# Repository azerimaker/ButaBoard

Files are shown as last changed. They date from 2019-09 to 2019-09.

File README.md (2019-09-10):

# ButaBoard
This repo contains all the necessary design, fabrication files and example codes for the ButaBoard development board. ButaBoard is highly inspired by the [Adafruit Circuit Playground Classic](https://www.adafruit.com/product/3000) with some minor hardware changes. Additionaly, the paisley patterned styling and ornamental touches make this board more suitable for wearables. 

## Specs:
- ATmega32u4 MCU, running @3.3V, 8MHz
- 32KB Flash, 2.5 KB SRAM, 1KB EEPROM
- IO pins: 14 (Crocodile clip-4mm Banana pads)
- On-board peripherals:
  - LIS3DH Accelerometer 
  - ALS-PT19-315C analog light sensor
  - AOS3729A analog microphone
  - NTC Temperature Sensor
  - Buzzer
  - 12x WS2812B RGB LEDs
  - 1x user button, 1x user LED
  - Power Switch
- Dimenions: ~94x61x5 mm

### ButaBoard v1
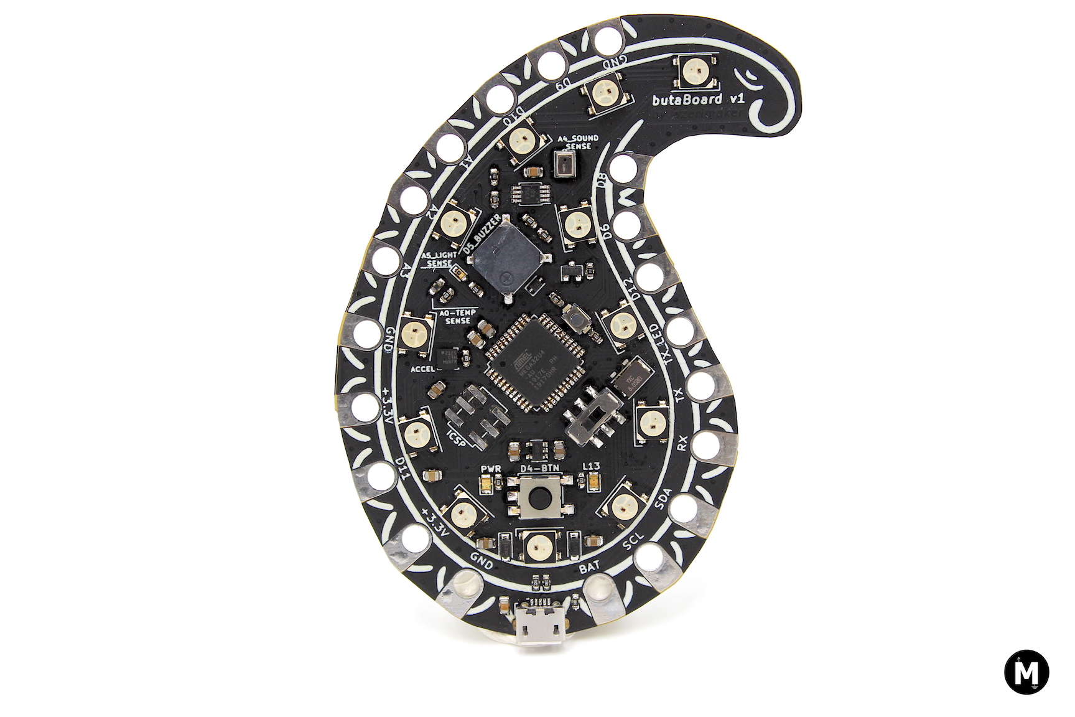
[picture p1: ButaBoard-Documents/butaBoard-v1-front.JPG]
ButaBoard v1 Front

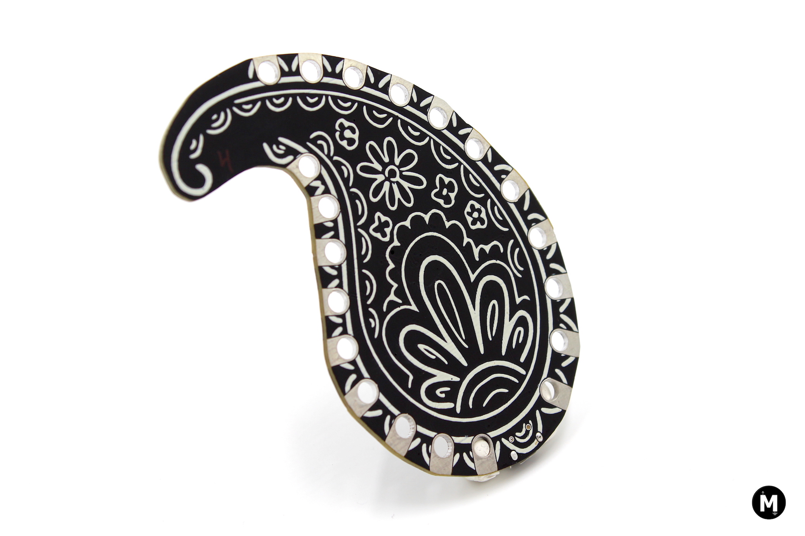
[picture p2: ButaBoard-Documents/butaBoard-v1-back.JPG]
ButaBoard v1 Back


<div align="center">
<br />This work is licensed under a <a rel="license" href="http://creativecommons.org/licenses/by-nc-sa/4.0/">Creative Commons Attribution-NonCommercial-ShareAlike 4.0 International License</a>.
</div>

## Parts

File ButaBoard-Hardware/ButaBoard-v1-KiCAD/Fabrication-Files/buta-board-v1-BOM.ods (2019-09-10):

Reference | Quantity | MPN | Value | Description | Package | URL
C11 | 1 |  | 100nF |  | 0805_2012Metric | ~
C2 C6 C1 C5 C10 | 5 |  | 1uF |  | 0805_2012Metric | ~
C3 C4 | 2 |  | 22pF |  | 0201_0603Metric | ~
C8 C7 C12 | 3 |  | 10uF |  | 0805_2012Metric | ~
C9 | 1 |  | 4.7nF |  | 0805_2012Metric | ~
D1 D3 | 2 | MBR120VLSFT1G | MBR120 | Schottky Barrier Diodes (SBD) SOD-123F RoHS | SMD:D_SOD-123 | https://lcsc.com/product-detail/Schottky-Barrier-Diodes-SBD_ON-Semicon_MBR120VLSFT1G_ON-Semicon-ON-MBR120VLSFT1G_C223608.html
D2 | 1 |  | Green |  | 0805_2012Metric | ~
D4 | 1 |  | RED |  | 0805_2012Metric | ~
D5 | 1 | 1N4148WS | 1N4148WS | Switching Diode 75V 150mA 1V @ 10mA 4ns SOD-323 RoHS | SOD-323 | https://lcsc.com/product-detail/Switching-Diode_1N4148WS_C110221.html
D6 D7 D8 D9 D10 D11 D12 D13 D14 D15 D17 D16 | 12 | WS2812B-B | WS2812B | Light Emitting Diodes (LED) RGB 620~630nm Red, 515~530nm Green, 465~475nm Blue 550~700mcd@16mA Red, 1100~1400mcd@16mA Green, 200~400mcd@16mA Blue Top View 5050 RoHS | LED_WS2812B_PLCC4_5.0x5.0mm_P3.2mm
J23 | 1 |  | ICSP |  | PinHeader_2x03_P2.54mm_Vertical_SMD | https://lcsc.com/product-detail/Light-Emitting-Diodes-LED_5050-RGBIntegrated-Light-4Pin_C114586.html
J6 | 1 | C10418 | USB_B_Micro | USB Connectors 5 Receptacle 1 SMD RoHS | USB_Micro-B_C10418 | https://lcsc.com/product-detail/USB-Connectors_Jing-Extension-of-the-Electronic-Co-LCSC-MICRO-USB-5S-B-Type-horns-High-temperature_C10418.html
LS1 | 1 | GSC8525RA-16R2700 | Buzzer 2700Hz | Buzzers Magnetic NO 2700Hz 3V 2 ~ 5V 8.5mm x 8.5mm SMD,8.5x8.5x3mm RoHS | SMD,8.5x8.5x3mm | https://lcsc.com/product-detail/Buzzers_INGHAi-GSC8525RA-16R2700_C255314.html
Q1 | 1 | FHT3265-ME | FHT3265 | Transistors (NPN/PNP) NPN 800mA 30V SOT-23(SOT-23-3) RoHS | SOT-23 | https://lcsc.com/product-detail/Others_Guangdong-Fenghua-Advanced-Tech-FHT3265-ME_C336156.html
Q2 | 1 | ALS-PT19-315C/L177/TR8 | ALS-PT19-315C | Ambient Light Sensors 1.7*0.8*0.6mm RoHS | D_0603_1608Metric – 1.7*0.8*0.6mm | https://lcsc.com/product-detail/Photoresistors_ALS-PT19-315C-L177-TR8_C146233.html
R1 R3 R13 R14 R15 R9 R12 | 7 |  | 10K |  | 0603_1608Metric | ~
R11 | 1 |  | 100K |  | 0603_1608Metric | ~
R2 R6 R8 R10 | 4 |  | 1K |  | 0603_1608Metric | ~
R4 R5 | 2 |  | 22R |  | 0603_1608Metric | ~
R7 | 1 |  | 1M |  | 0603_1608Metric | ~
SW1 | 1 | B3U-1000P-B | ~RESET |  | SW_SPST_B3U-1000P-B | ~
SW2 | 1 | K3-2235S-F1 | SW_SPDT | 9.0mm*3.5mm SMD | MSS22D18 | https://lcsc.com/product-detail/Toggle-Switches_Korean-Hroparts-Elec-K3-2235S-F1_C223858.html
SW3 | 1 | SKHMQKE010 | PUSH_BTN | Tactile Switches SPST-NO 6.50mm x 6.20mm 3.10mm 50mA @ 12VDC SMD RoHS | SKHMQKE010_PushButton | https://lcsc.com/product-detail/Tactile-Switches_ALPS_SKHMQKE010_SKHMQKE010_C202416.html
TH1 | 1 | SDNT1608X103F3380FTF | 10K 1% NTC | NTC Thermistors 1/10W 10KOhms ±1% 3380K 0603 RoHS | 0603_1608Metric_Pad1.05x0.95mm_HandSolder | https://lcsc.com/product-detail/Others_Sunlord-SDNT1608X103F3380FTF_C316397.html
U1 | 1 | AP2112K-3.3TRG1 | AP2112K-3.3 | Low Dropout Regulators(LDO) SOT-25 RoHS | SOT-23-5 | https://lcsc.com/product-detail/Low-Dropout-Regulators-LDO_DIODES_AP2112K-3-3TRG1_AP2112K-3-3TRG1_C51118.html
U2 | 1 | LIS3DH | LIS3DH |  | LGA-16_3x3mm_P0.5mm_LayoutBorder3x5y | Aliexpress
U3 | 1 | ATmega32U4-AU | ATmega32U4-AU | ATMEL & AVR QFP-44_10x10x08P RoHS | TQFP-44_10x10mm_P0.8mm | https://lcsc.com/product-detail/ATMEL-AVR_ATMEL_ATMEGA32U4-AU_ATMEGA32U4-AU_C44854.html
U4 | 1 | LMV358DMR2G | LMV358DMR2G | General Purpose Amplifiers General Purpose 2 2.7V ~ 5.5V 1MHz 1 V/us MSOP-8 RoHS | MSOP-8_3x3mm_P0.65mm | https://lcsc.com/product-detail/General-Purpose-Amplifiers_ON-Semicon_LMV358DMR2G_ON-Semicon-ON-LMV358DMR2G_C128007.html
U5 | 1 | AOS3729A | AOS3729A | Electret Condenser Microphone SMD,3.76x2.95x1.10mm RoHS | AOS3729A-T42-NXC-MIC | https://lcsc.com/product-detail/Others_SANICO-AOS3729A-T42-NXC_C338759.html
Y1 | 1 | X50328MSB2GI | 8MHz | Tactile Switches SPST-NO 6.50mm x 6.20mm 3.10mm 50mA @ 12VDC SMD RoHS | Crystal_SMD_5032-2Pin_5.0x3.2mm | https://lcsc.com/product-detail/SMD-Crystal-Resonators_Yangxing-Tech-X50328MSB2GI_C115962.html

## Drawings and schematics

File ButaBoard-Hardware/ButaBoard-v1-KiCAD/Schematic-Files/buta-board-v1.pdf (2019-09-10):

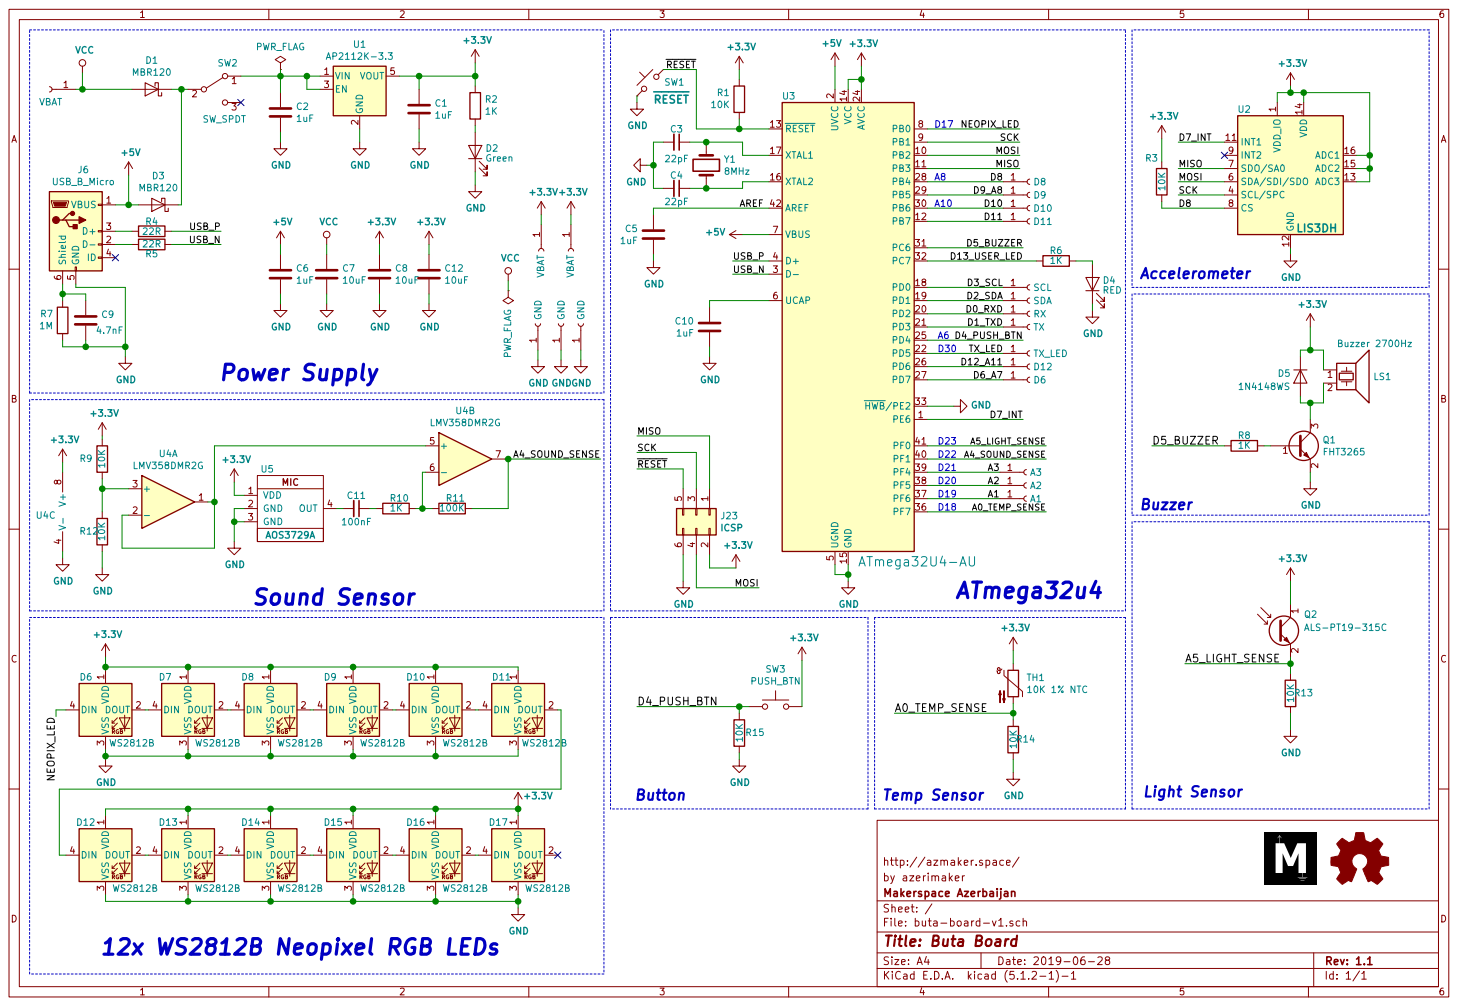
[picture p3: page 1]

2 PD2 20 PD3 21 PD5 22 AVCC 24 PD4 25 PD6 26 PD7 27 PB4 28 PB5 29 D- 3 PB6 30 PC6 31 PC7 32 HWB/PE2 33 PF7 36 PF6 37 PF5 38 PF4 39 D+ 4 PF1 40 PF0 41 AREF 42 UGND

http://azmaker.space/
by azerimaker
File: buta-board-v1.sch Sheet: / Makerspace Azerbaijan

Id: 1/1 Title: Buta Board

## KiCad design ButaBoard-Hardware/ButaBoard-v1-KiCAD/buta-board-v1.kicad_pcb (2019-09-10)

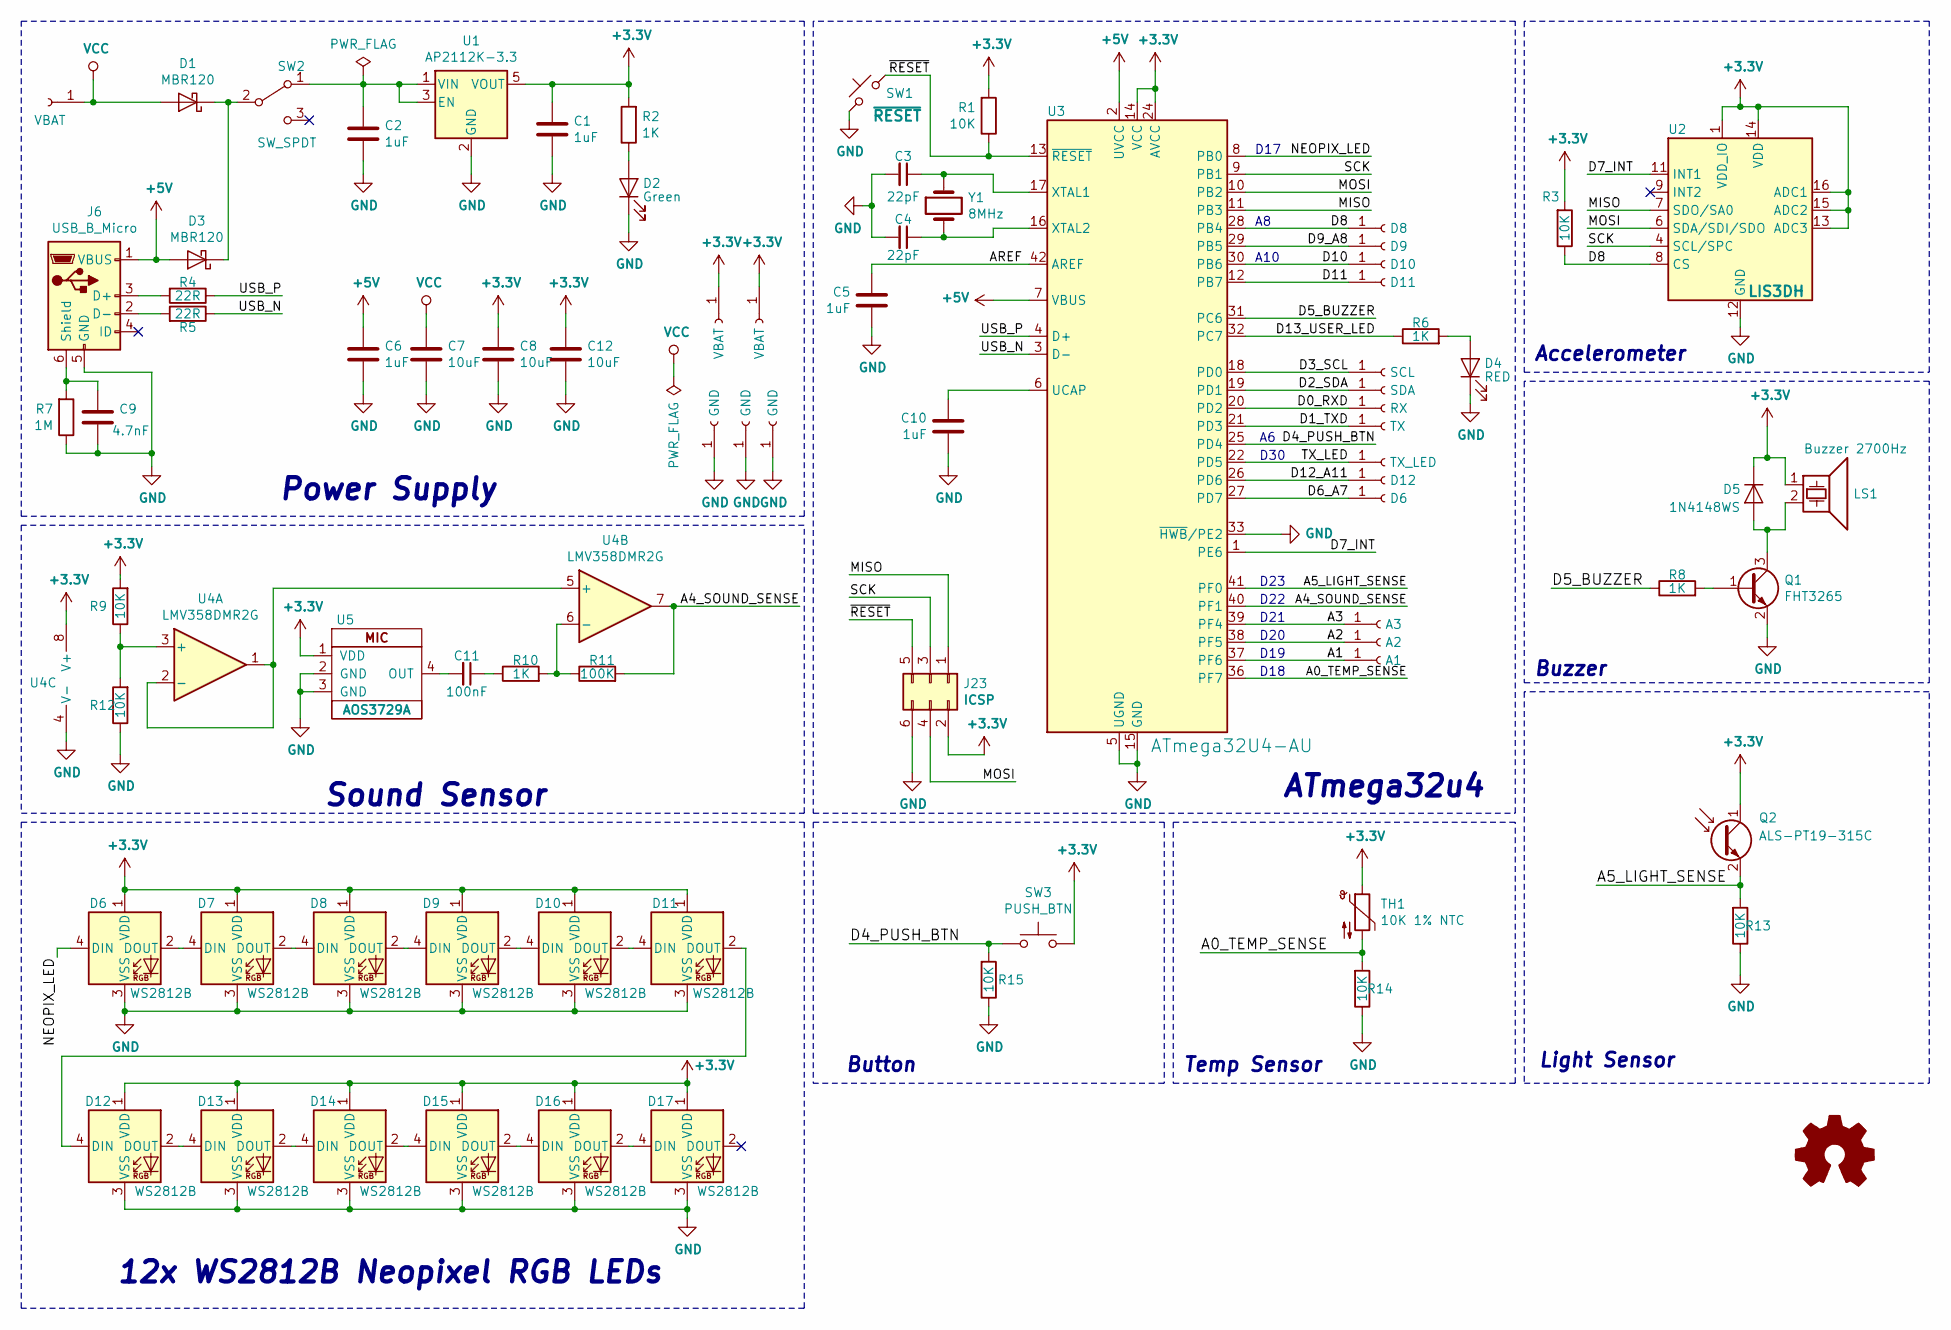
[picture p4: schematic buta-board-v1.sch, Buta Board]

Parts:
C1, C2, C5, C6, C10: 1uF; C_0805_2012Metric
C3, C4: 22pF; C_0402_1005Metric
C7, C8, C12: 10uF; C_0805_2012Metric
C9: 4.7nF; C_0805_2012Metric
C11: 100nF; C_0805_2012Metric
D1, D3: MBR120; D_SOD-123; MPN MBR120VLSFT1G
D2: Green; LED_0805_2012Metric
D4: RED; LED_0805_2012Metric
D5: 1N4148WS; D_SOD-323; MPN 1N4148WS
D6, D7, D8, D9, D10, D11, D12, D13, D14, D15, D16, D17: WS2812B; LED_WS2812B_PLCC4_5.0x5.0mm_P3.2mm; MPN WS2812B-B
J2: D8; Alligator_Pads
J3: D9; Alligator_Pads
J4: D10; Alligator_Pads
J5: D11; Alligator_Pads
J6: USB_B_Micro; USB_Micro-B_C10418; MPN C10418
J7, J8, J9: GND; Alligator_Pads
J10: SCL; Alligator_Pads
J11: SDA; Alligator_Pads
J12, J14, J15: VBAT; Alligator_Pads
J13: RX; Alligator_Pads
J16: TX; Alligator_Pads
J17: TX_LED; Alligator_Pads
J18: D12; Alligator_Pads
J19: D6; Alligator_Pads
J20: A3; Alligator_Pads
J21: A2; Alligator_Pads
J22: A1; Alligator_Pads
J23: ICSP; PinHeader_2x03_P2.54mm_Vertical_SMD
LS1: Buzzer 2700Hz; GSC8525RA-16R2700; MPN GSC8525RA-16R2700
Q1: FHT3265; SOT-23; MPN FHT3265-ME
Q2: ALS-PT19-315C; D_0603_1608Metric; MPN ALS-PT19-315C/L177/TR8
R1, R3, R9, R12, R13, R14, R15: 10K; R_0603_1608Metric
R2, R6, R8, R10: 1K; R_0603_1608Metric
R4, R5: 22R; R_0603_1608Metric
R7: 1M; R_0603_1608Metric
R11: 100K; R_0603_1608Metric
SW1: ~RESET; SW_SPST_B3U-1000P-B; MPN B3U-1000P-B
SW2: SW_SPDT; MSS22D18; MPN K3-2235S-F1
SW3: PUSH_BTN; SKHMQKE010_PushButton; MPN SKHMQKE010
TH1: 10K 1% NTC; R_0603_1608Metric_Pad1.05x0.95mm_HandSolder; MPN SDNT1608X103F3380FTF
U1: AP2112K-3.3; SOT-23-5; MPN AP2112K-3.3TRG1
U2: LIS3DH; LGA-16_3x3mm_P0.5mm_LayoutBorder3x5y
U3: ATmega32U4-AU; TQFP-44_10x10mm_P0.8mm
U4: LMV358DMR2G; MSOP-8_3x3mm_P0.65mm; MPN LMV358DMR2G
U5: AOS3729A; AOS3729A-T42-NXC-MIC
Y1: 8MHz; Crystal_SMD_5032-2Pin_5.0x3.2mm; MPN X50328MSB2GI

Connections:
+3V3: C1.1, C8.1, C12.1, D5.1 (K), D6.1 (VDD), D7.1 (VDD), D8.1 (VDD), D9.1 (VDD), D10.1 (VDD), D11.1 (VDD), D12.1 (VDD), D13.1 (VDD), D14.1 (VDD), D15.1 (VDD), D16.1 (VDD), D17.1 (VDD), J14.1, J15.1, J23.2, LS1.1, Q2.1 (C), R1.2, R2.2, R3.2, R9.2, SW3.2, TH1.1, U1.5 (VOUT), U2.1 (VDD_IO), U2.13 (ADC3), U2.14 (VDD), U2.15 (ADC2), U2.16 (ADC1), U3.14 (VCC), U3.24 (AVCC), U3.34 (VCC), U3.44 (AVCC), U4.8 (V+), U5.1 (VDD)
+5V: C6.1, D3.2 (A), J6.1 (VBUS), U3.2 (UVCC), U3.7 (VBUS)
/A0_TEMP_SENSE: R14.2, TH1.2, U3.36 (PF7)
/A1: J22.1, U3.37 (PF6)
/A2: J21.1, U3.38 (PF5)
/A3: J20.1, U3.39 (PF4)
/A4_SOUND_SENSE: R11.2, U3.40 (PF1), U4.7
/A5_LIGHT_SENSE: Q2.2 (E), R13.2, U3.41 (PF0)
/AREF: C5.1, U3.42 (AREF)
/D0_RXD: J13.1, U3.20 (PD2)
/D1_TXD: J16.1, U3.21 (PD3)
/D2_SDA: J11.1, U3.19 (PD1)
/D3_SCL: J10.1, U3.18 (PD0)
/D4_PUSH_BTN: R15.2, SW3.1, U3.25 (PD4)
/D5_BUZZER: R8.1, U3.31 (PC6)
/D6_A7: J19.1, U3.27 (PD7)
/D7_INT: U2.11 (INT1), U3.1 (PE6)
/D8: J2.1, R3.1, U2.8 (CS), U3.28 (PB4)
/D9_A8: J3.1, U3.29 (PB5)
/D10: J4.1, U3.30 (PB6)
/D11: J5.1, U3.12 (PB7)
/D12_A10: J18.1, U3.26 (PD6)
/D13_USER_LED: R6.1, U3.32 (PC7)
/MISO: J23.1, U2.7 (SDO/SA0), U3.11 (PB3)
/MOSI: J23.4, U2.6 (SDA/SDI/SDO), U3.10 (PB2)
/NEOPIX_LED: D6.4 (DIN), U3.8 (PB0)
/SCK: J23.3, U2.4 (SCL/SPC), U3.9 (PB1)
/TX_LED: J17.1, U3.22 (PD5)
/USB_N: R5.1, U3.3 (D-)
/USB_P: R4.1, U3.4 (D+)
/~RESET: J23.5, R1.1, SW1.2, U3.13 (~RESET)
GND: C1.2, C2.2, C3.2, C4.2, C5.2, C6.2, C7.2, C8.2, C9.2, C10.2, C12.2, D2.1 (K), D4.1 (K), D6.3 (VSS), D7.3 (VSS), D8.3 (VSS), D9.3 (VSS), D10.3 (VSS), D11.3 (VSS), D12.3 (VSS), D13.3 (VSS), D14.3 (VSS), D15.3 (VSS), D16.3 (VSS), D17.3 (VSS), J6.5 (GND), J7.1, J8.1, J9.1, J23.6, Q1.2 (E), R7.1, R12.1, R13.1, R14.1, R15.1, SW1.1, U1.2 (GND), U2.5 (GND), U2.10 (GND), U2.12 (GND), U3.5 (UGND), U3.15 (GND), U3.23 (GND), U3.33 (~HWB~/PE2), U3.35 (GND), U3.43 (GND), U4.4 (V-), U5.2 (GND), U5.3 (GND)
unnamed: C2.1, SW2.1 (A), U1.1 (VIN), U1.3 (EN)
unnamed: C3.1, U3.17 (XTAL1), Y1.1
unnamed: C4.1, U3.16 (XTAL2), Y1.2
unnamed: C9.1, J6.6 (Shield), R7.2
unnamed: C10.1, U3.6 (UCAP)
unnamed: C11.1, R10.1
unnamed: C11.2, U5.4 (OUT)
unnamed: D1.1 (K), D3.1 (K), SW2.2 (B)
unnamed: D2.2 (A), R2.1
unnamed: D4.2 (A), R6.2
unnamed: D5.2 (A), LS1.2, Q1.3 (C)
unnamed: D6.2 (DOUT), D7.4 (DIN)
unnamed: D7.2 (DOUT), D8.4 (DIN)
unnamed: D8.2 (DOUT), D9.4 (DIN)
unnamed: D10.2 (DOUT), D11.4 (DIN)
unnamed: D9.2 (DOUT), D10.4 (DIN)
unnamed: D11.2 (DOUT), D12.4 (DIN)
unnamed: D12.2 (DOUT), D13.4 (DIN)
unnamed: D13.2 (DOUT), D14.4 (DIN)
unnamed: D14.2 (DOUT), D15.4 (DIN)
unnamed: D15.2 (DOUT), D16.4 (DIN)
unnamed: D16.2 (DOUT), D17.4 (DIN)
unnamed: J6.2 (D-), R5.2
unnamed: J6.3 (D+), R4.2
unnamed: Q1.1 (B), R8.2
unnamed: R10.2, R11.1, U4.6 (-)
unnamed: R9.1, R12.2, U4.3 (+)
unnamed: U4.1, U4.2 (-), U4.5 (+)
VCC: C7.1, D1.2 (A), J12.1

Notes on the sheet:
Power Supply
12x WS2812B Neopixel RGB LEDs
ATmega32u4
Sound Sensor
Accelerometer
Buzzer
Light Sensor
Temp Sensor
Button
D17
A10
D30
D23
D22
D18
D20
D21
D19

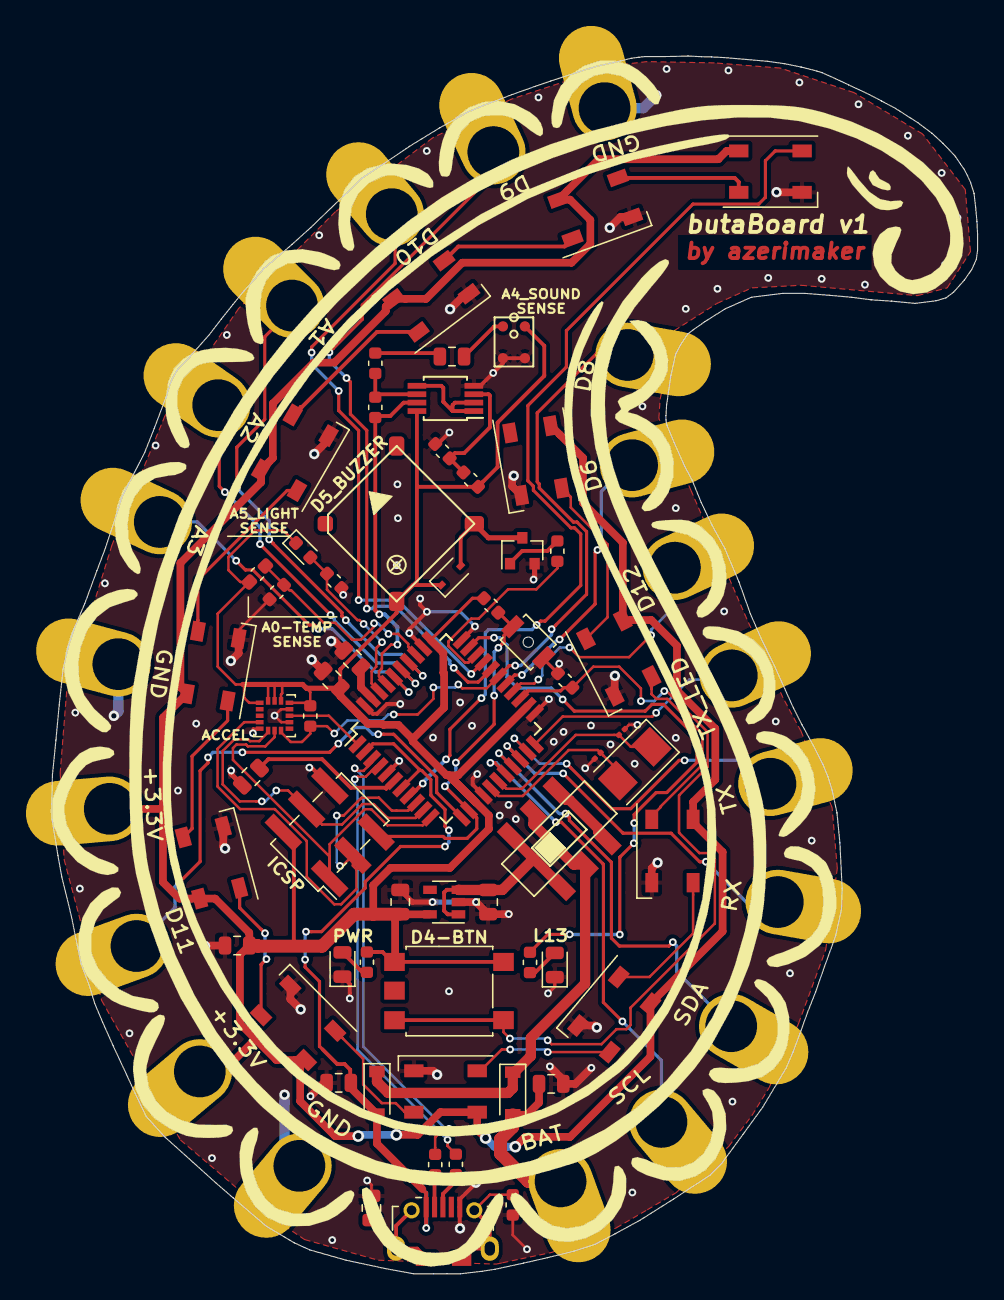
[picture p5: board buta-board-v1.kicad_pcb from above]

Board: 2 copper layers, 71.6 x 94.2 mm, 79 parts (0 on the bottom side), 61 nets.

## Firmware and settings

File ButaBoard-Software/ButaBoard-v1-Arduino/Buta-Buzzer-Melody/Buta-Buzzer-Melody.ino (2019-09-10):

/*
This sketch uses the buzzer to play songs.
The Arduino's tone() command will play notes of a given frequency.
We'll provide a function that takes in note characters (a-g),
and returns the corresponding frequency from this table:

  note  frequency
  c     262 Hz
  d     294 Hz
  e     330 Hz
  f     349 Hz
  g     392 Hz
  a     440 Hz
  b     494 Hz
  C     523 Hz

For more information, see http://arduino.cc/en/Tutorial/Tone
*/

const int buzzerPin = 5;

// We'll set up an array with the notes we want to play
// change these values to make different songs!

// Length must equal the total number of notes and spaces 

const int songLength = 18;

// Notes is an array of text characters corresponding to the notes
// in your song. A space represents a rest (no tone)

char notes[] = "cdfda ag cdfdg gf "; // a space represents a rest

// Beats is an array of values for each note and rest.
// A "1" represents a quarter-note, 2 a half-note, etc.
// Don't forget that the rests (spaces) need a length as well.

int beats[] = {1,1,1,1,1,1,4,4,2,1,1,1,1,1,1,4,4,2};

// The tempo is how fast to play the song.
// To make the song play faster, decrease this value.

int tempo = 113;


void setup() 
{
  pinMode(buzzerPin, OUTPUT);
}


void loop() 
{
  int i, duration;

  for (i = 0; i < songLength; i++) // step through the song arrays
  {
    duration = beats[i] * tempo;  // length of note/rest in ms

    if (notes[i] == ' ')          // is this a rest? 
    {
      delay(duration);            // then pause for a moment
    }
    else                          // otherwise, play the note
    {
      tone(buzzerPin, frequency(notes[i]), duration);
      delay(duration);            // wait for tone to finish
    }
    delay(tempo/10);              // brief pause between notes
  }

  // We only want to play the song once, so we'll pause forever:
 // while(true){}
  // If you'd like your song to play over and over,
  // remove the above statement
}


int frequency(char note) 
{
  // This function takes a note character (a-g), and returns the
  // corresponding frequency in Hz for the tone() function.

  int i;
  const int numNotes = 8;  // number of notes we're storing

  // The following arrays hold the note characters and their
  // corresponding frequencies. The last "C" note is uppercase
  // to separate it from the first lowercase "c". If you want to
  // add more notes, you'll need to use unique characters.

  // For the "char" (character) type, we put single characters
  // in single quotes.

  char names[] = { 'c', 'd', 'e', 'f', 'g', 'a', 'b', 'C' };
  int frequencies[] = {262, 294, 330, 349, 392, 440, 494, 523};

  // Now we'll search through the letters in the array, and if
  // we find it, we'll return the frequency for that note.

  for (i = 0; i < numNotes; i++)  // Step through the notes
  {
    if (names[i] == note)         // Is this the one?
    {
      return(frequencies[i]);     // Yes! Return the frequency
    }
  }
  return(0);  // We looked through everything and didn't find it,
              // but we still need to return a value, so return 0.
}

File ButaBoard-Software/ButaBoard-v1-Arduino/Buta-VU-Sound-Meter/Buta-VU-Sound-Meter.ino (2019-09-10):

/*
LED VU meter for Arduino and NeoPixel LEDs.
https://www.instructables.com/id/Neo-Pixel-Arduino-Vu-Meter/
*/

#include <Adafruit_NeoPixel.h>

#define N_PIXELS  12  // Number of pixels in strand
#define MIC_PIN   A4   // Microphone is attached to this analog pin
#define LED_PIN    17  // NeoPixel LED strand is connected to this pin
#define DC_OFFSET  0  // DC offset in mic signal - if unusure, leave 0
#define NOISE     20  // Noise/hum/interference in mic signal
#define SAMPLES   40  // Length of buffer for dynamic level adjustment
#define TOP       (N_PIXELS + 0) // Allow dot to go slightly off scale
#define PEAK_FALL 40  // Rate of peak falling dot

byte
  peak      = 0,      // Used for falling dot
  dotCount  = 0,      // Frame counter for delaying dot-falling speed
  volCount  = 0;      // Frame counter for storing past volume data
int
  vol[SAMPLES],       // Collection of prior volume samples
  lvl       = 60,      // Current "dampened" audio level
  minLvlAvg = 0,      // For dynamic adjustment of graph low & high
  maxLvlAvg = 512;
Adafruit_NeoPixel buta = Adafruit_NeoPixel(N_PIXELS, LED_PIN, NEO_GRB + NEO_KHZ800);

void setup() {
  memset(vol, 0, sizeof(vol));
  buta.begin();
}

void loop() {
  uint8_t  i;
  uint16_t minLvl, maxLvl;
  int      n, height;



  n   = analogRead(MIC_PIN);                  // Raw reading from mic
  n   = abs(n - 512 - DC_OFFSET); // Center on zero
  n   = (n <= NOISE) ? 0 : (n - NOISE);             // Remove noise/hum
  lvl = ((lvl * 7) + n) >> 3;    // "Dampened" reading (else looks twitchy)

  // Calculate bar height based on dynamic min/max levels (fixed point):
  height = TOP * (lvl - minLvlAvg) / (long)(maxLvlAvg - minLvlAvg);

  if(height < 0L)       height = 0;      // Clip output
  else if(height > TOP) height = TOP;
  if(height > peak)     peak   = height; // Keep 'peak' dot at top


  // Color pixels based on rainbow gradient
  for(i=0; i<N_PIXELS; i++) {
    if(i >= height)               buta.setPixelColor(i,   0,   0, 0);
    else buta.setPixelColor(i,Wheel(map(i,0,buta.numPixels()-1,30,150)));
   
  }

  // Draw peak dot 
  if(peak > 0 && peak <= N_PIXELS-1) buta.setPixelColor(peak,Wheel(map(peak,0,buta.numPixels()-1,30,150)));
 
   buta.show(); // Update buta

// Every few frames, make the peak pixel drop by 1:

    if(++dotCount >= PEAK_FALL) { //fall rate
     
      if(peak > 0) peak--;
      dotCount = 0;
    }



  vol[volCount] = n;                      // Save sample for dynamic leveling
  if(++volCount >= SAMPLES) volCount = 0; // Advance/rollover sample counter

  // Get volume range of prior frames
  minLvl = maxLvl = vol[0];
  for(i=1; i<SAMPLES; i++) {
    if(vol[i] < minLvl)      minLvl = vol[i];
    else if(vol[i] > maxLvl) maxLvl = vol[i];
  }
  // minLvl and maxLvl indicate the volume range over prior frames, used
  // for vertically scaling the output graph (so it looks interesting
  // regardless of volume level).  If they're too close together though
  // (e.g. at very low volume levels) the graph becomes super coarse
  // and 'jumpy'...so keep some minimum distance between them (this
  // also lets the graph go to zero when no sound is playing):
  if((maxLvl - minLvl) < TOP) maxLvl = minLvl + TOP;
  minLvlAvg = (minLvlAvg * 63 + minLvl) >> 6; // Dampen min/max levels
  maxLvlAvg = (maxLvlAvg * 63 + maxLvl) >> 6; // (fake rolling average)

}

// Input a value 0 to 255 to get a color value.
// The colors are a transition r - g - b - back to r.
uint32_t Wheel(byte WheelPos) {
  if(WheelPos < 85) {
   return buta.Color(WheelPos * 3, 255 - WheelPos * 3, 0);
  } else if(WheelPos < 170) {
   WheelPos -= 85;
   return buta.Color(255 - WheelPos * 3, 0, WheelPos * 3);
  } else {
   WheelPos -= 170;
   return buta.Color(0, WheelPos * 3, 255 - WheelPos * 3);
  }
}

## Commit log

2019-09-10 Design files added
    Design files for v1
    [buta-board-v1-BOM.ods, buta-board-v1-BOM.xlsx, buta-board-v1.kicad_pcb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]
2019-09-10 Folder Structure Update
    [buta-board-v1-BOM.ods, buta-board-v1-BOM.xlsx, buta-board-v1.kicad_pcb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]
